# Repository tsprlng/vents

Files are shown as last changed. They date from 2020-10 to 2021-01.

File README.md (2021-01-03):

3D Printing of Vent Grilles
===========================

When I moved into a flat in the past, it had a ducted MVHR system which was missing a couple of vent grilles. The 122x122mm grilles weren't available anywhere convenient, so I decided to print my own at London Hackspace using PLA filament.

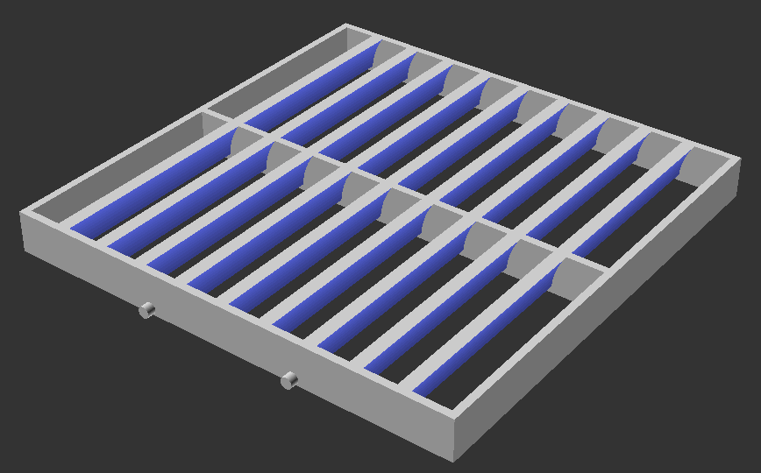
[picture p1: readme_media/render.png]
Render of grille designe


The shape of this grille is defined using OpenSCAD, an interesting declarative programming language for 3D modelling. For most things (especially this kind of simple repetitive collection of shapes with real world dimensions), I find it much more convenient and quick than using a GUI-based modeller. It's also much quicker to learn -- the whole language fits on a single sheet of paper.

You can view the design in 3D at [Thingiverse](https://www.thingiverse.com/thing:4634258).

There's Always (At Least) One Mistake
-------------------------------------

I needed two of these, and foolishly printed the first one without any kind of brim or raft. Predictably, with this relatively wide model, the bottom layers didn't have enough adhesion to the printer bed, and peeled up at the corners.

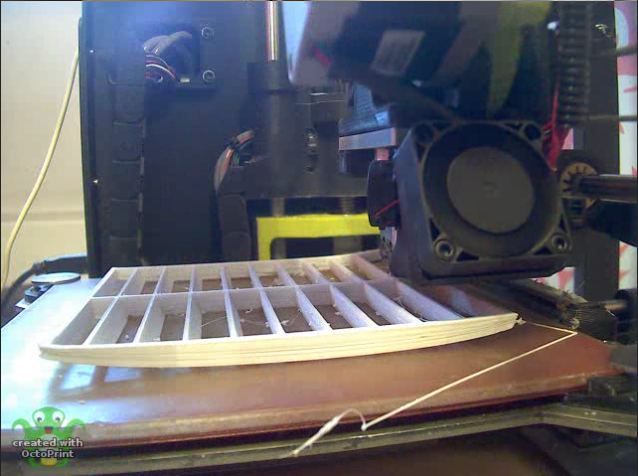
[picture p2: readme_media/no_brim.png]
Photo of curved grille being printed


Interestingly, this resulted in a curvy version of the grille that still fit the frame in the wall perfectly! Nonetheless, the second version -- re-sliced with a decently wide raft generated to increase adhesion -- came out much more neatly and tidily.

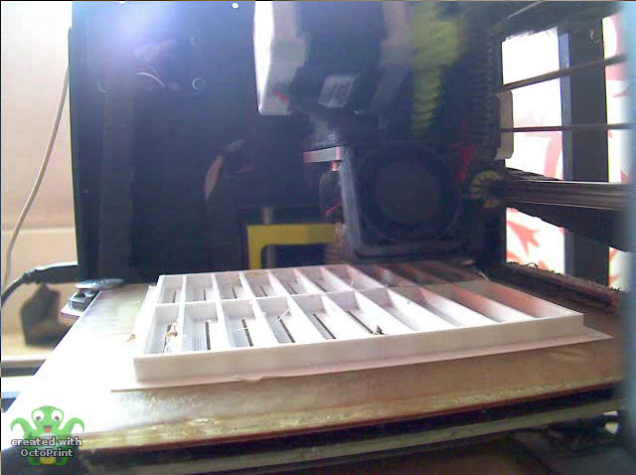
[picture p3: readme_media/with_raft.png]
Photo of improved grille being printed


- [Video of first (curved) print](readme_media/no_brim.mpg)
- [Video of second (improved) print](readme_media/with_raft.mpg)

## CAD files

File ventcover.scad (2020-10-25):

// overall dimensions (mm)
depth=11;
outer=122;
thickness=2;  // thickness of frame

slatsCount=9;

// dimension of side holding-in blobs (mm)
blobProjection=2.2;
blobRadius=1.5;

// manual creation of supports for printing blobs (unused)
propThickness=0.8;

// smoothly curved slat shape (difference between two different-radiused cylinders, within the cross-section of the frame)
module slat(){
	rotate([0, 90, 0]){
		intersection(){
			translate([8, -1, 0]){ difference(){
				cylinder(
					h=outer,
					r=12,
					$fn = 100,
					center=true);
				translate([7, 6, 0])
					cylinder(
						h=outer,
						r=18,
						$fn = 100,
						center=true);
			}}
			cube([depth, depth, outer], center=true);
		}
	}
}

module vent(){
	// slats
	slatSpacing = (outer-thickness) / (slatsCount+1);
	for (slatNumber = [1:slatsCount]){
		translate([0, 0, (outer - 2*thickness)/2 - (slatNumber*slatSpacing)])
			slat();
	}
	
	// frame
	for (side = [0:90:270]) {
		rotate([0, side, 0])
			translate([(outer-thickness)/2, 0, 0])
				cube([thickness, depth, outer], center=true);
	}
	
	// vertical brace down the middle of the frame
	cube([thickness, depth, outer], center=true);
	
	// side blobs
	blobXOffset = (outer+blobProjection)/2;
	for (x = [-blobXOffset, blobXOffset]){
		for (z = [-(outer/6), outer/6]){
			// actual blob
			translate([x, depth/2-blobRadius, z])
				rotate([0, 90, 0])
				cylinder(
					h=blobProjection,
					r=blobRadius,
					$fn = 100,
					center=true);
		
			// manual creation of supports for printing blobs (unused)
			// translate([x, 0, z])
			// cube([blobProjection, depth, propThickness], center=true);
		}
	}
}

color("lightgrey")
translate([0, 0, depth/2])
rotate([90, 0, 0])
vent();
